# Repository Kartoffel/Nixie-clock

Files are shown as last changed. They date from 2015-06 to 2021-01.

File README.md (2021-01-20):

# Nixie-clock
DIY IN-14 Nixie clock

### Read the article at https://blankers.eu/2021/nixie-clock/

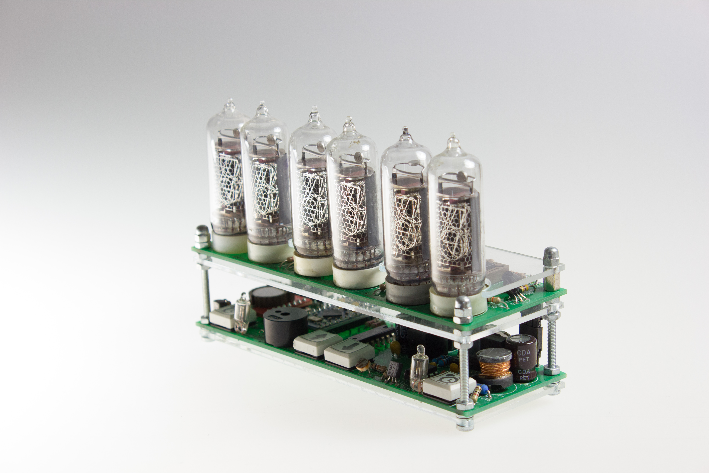
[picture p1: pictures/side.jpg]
Nixie clock


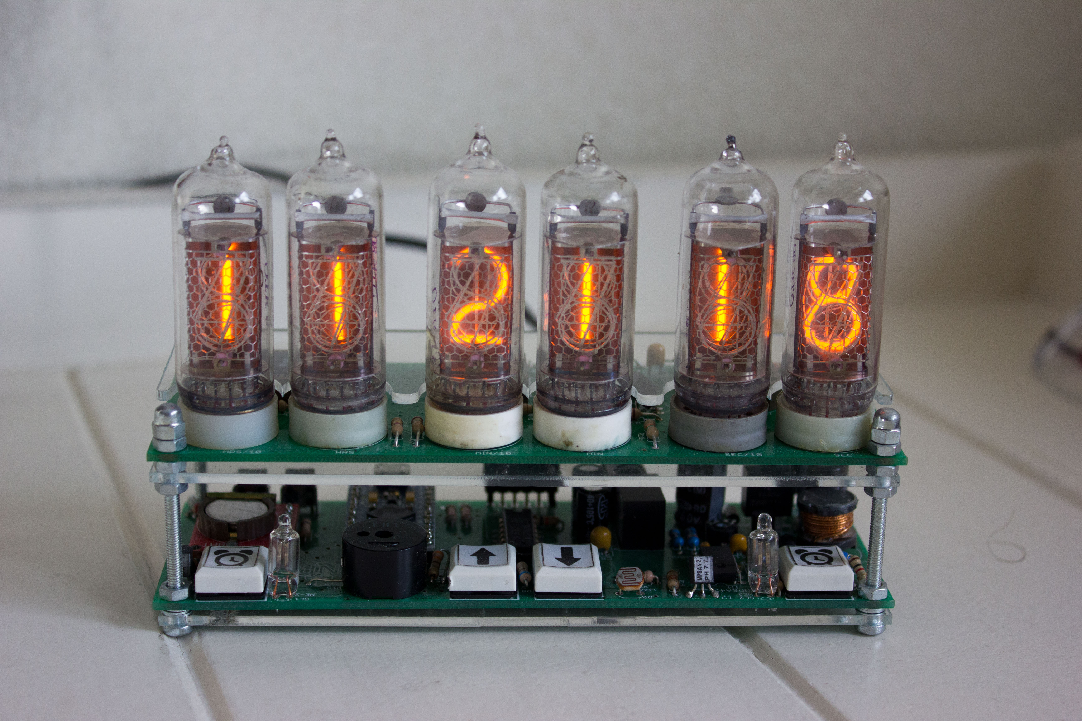
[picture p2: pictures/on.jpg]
Nixie clock in operation


<a href="http://www.youtube.com/watch?feature=player_embedded&v=HqRzXS7RQFY" target="_blank">Demonstration video</a>

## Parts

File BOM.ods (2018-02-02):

Part | Name | Part number
 | 6x Nixie tube | IN14
IC1..IC3 | VFD driver IC | HV5812PJ
T3 | PNP high voltage transistor | MPSA92
T4,T7 | NPN high voltage transistor | MPSA42
D6 | Zener diode 62V | Zen-1-3W-62V
C9 | 100nF capacitor (>62V) 0.1” | 100nF-R2-5
R4 | Resistor 390K | Kool-0W5-390k
R16 | Resistor 33K | Kool-0W5-33k
R1,R21 | Resistor 10K | Kool-0W5-10k
R13 | Resistor 470K | Kool-0W5-470k
R3,R6,R7,R10,R11,R14 | Resistor 15K | Kool-0W5-15k
R2,R15 | Resistor 120K | Kool-0W5-120k
JP2,JP3 | Pin headers 0.1” 6 pins lang | Head-6p-recht-Lang
JP2,JP3 | Pin header female 8 pins | ZL262-8
 | PCB 5x15cm 2 layers
U1 | SMPS | MC34063A
T8 | MOSFET | IRF640N
D2 | Diode | UF4007
L1 | Inductor 150uH | CH6080-150u
TR1 | Trimpot | Piher-ML-2k5
T9 | Transistor | BC516
D3 | Diode | SB140
R17 | Resistor 0R1 3W | DRG-3W-0r1
C2 | Capacitor 470uF 25V | 470uF-25V-Nichi-SE
C3,C6 | Capacitor 100nF | 100nF-R2-5
C4 | Capacitor 1nF | 1nF-R2-5
R18 | Resistor 1K | Kool-0W5-1k
R19 | Resistor 3K9 | Kool-0W5-3k9
R20 | Resistor 560K | Kool-0W5-560k
C5 | Capacitor 10uF 200V | 10uF-200V-kme
 | Power adapter 9V >=5W c. pos
JP1 | 2.1mm power jack | V-C-2mm1-DC10
U2 | Arduino pro micro
V1 | Quad 2-input AND gate | 74HCT08
IC1 | +5V LDO regulator | L4941BV
C8,C9 | Capacitor 100nF | 100nF-R2-5
C1,C7 | Capacitor 68uF | 68uF-25V-Pana-FR
R4,R5,R3 | Resistor 10K | Kool-0W5-10k
R15 | Resistor 180R | Kool-0W5-180
U3 | GeeTech RTC Module
SG1 | Buzzer | BZPN-1705
S1,S2 | Switch standing | DrukT-Haaks-Print-Wit
SW1-4 | Switch square white | Druktoets-Vierk-Print-wit
R2 | LDR | LDR-07-62
R13,R14 | Resistor 33K | Kool-0W5-33k
R1,R6 | Resistor 270K | Kool-0W5-270k
T1,T2 | High voltage transistor | MPSA42
GL1-2 | Neon bulbs | Neon-draad-15x5-8
R11,R12,R7 | Resistor 2K2 | Kool-0W5-2k2
R8 | Resistor 330R | Kool-0W5-330
R9 | Resistor 680R | Kool-0W5-680
R10 | Resistor 1K | Kool-0W5-1k
 | PCB 5x15cm 2 layers
 | Nuts/bolts/caps
 | 2mm acrylics (~15x15cm)

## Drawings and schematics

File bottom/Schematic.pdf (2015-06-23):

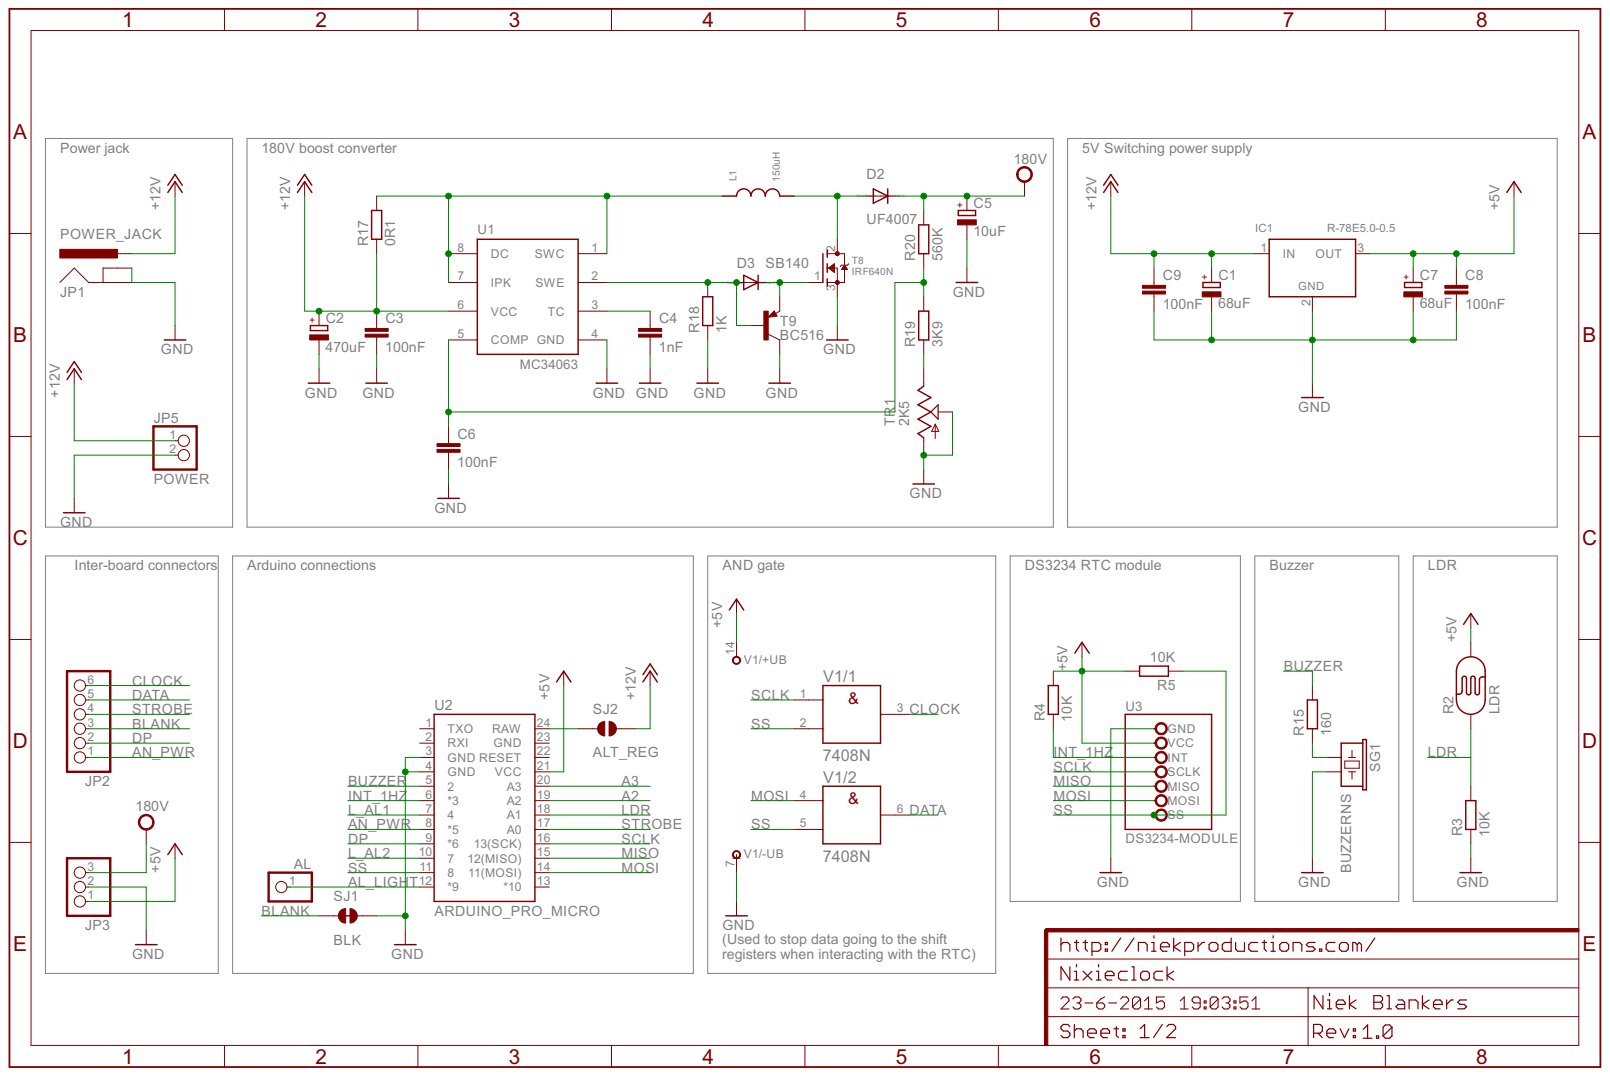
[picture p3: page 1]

GND
(Used to stop data going to the shift registers when interacting with the RTC)

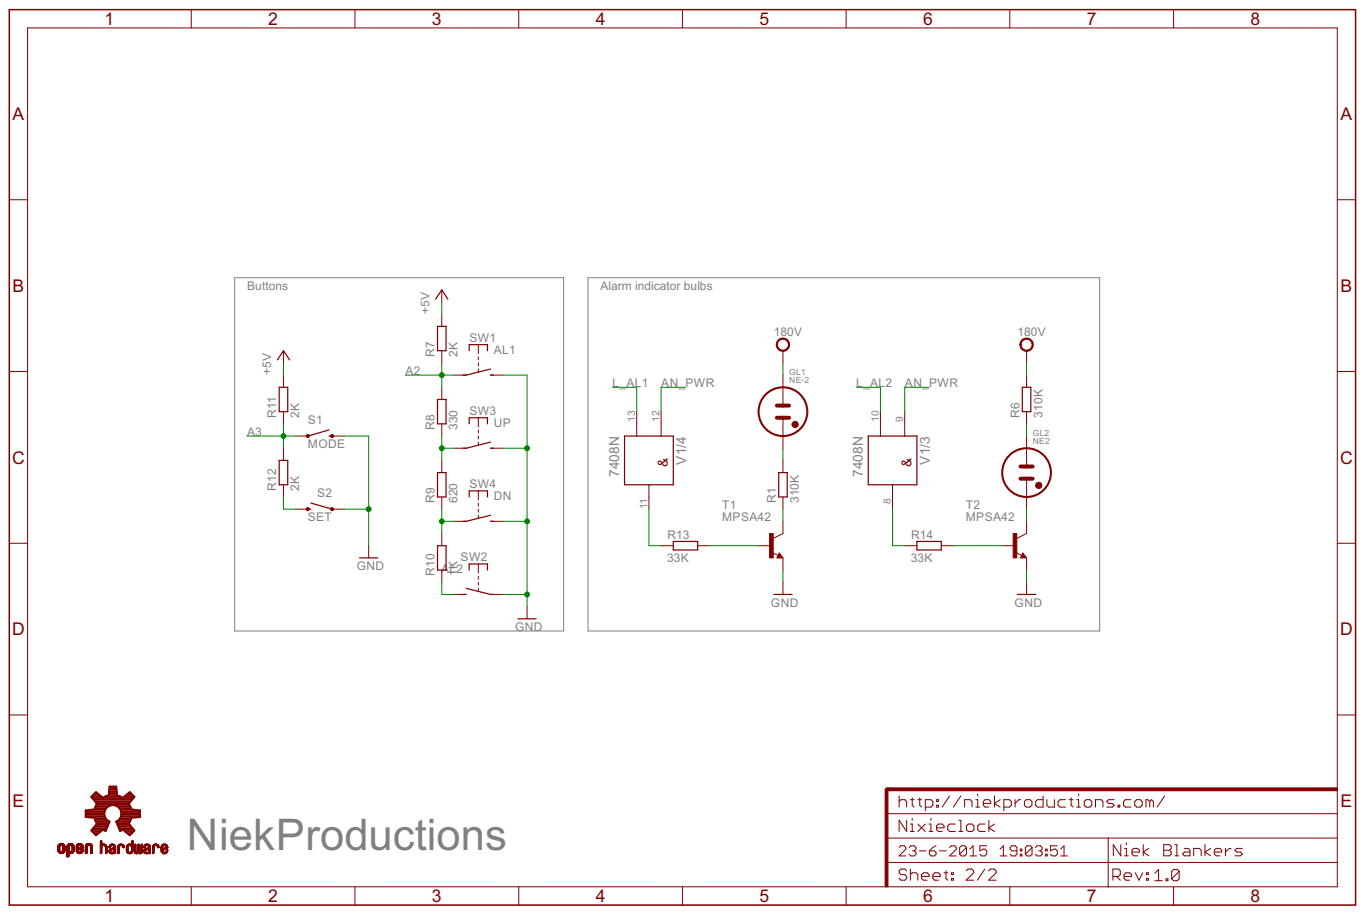
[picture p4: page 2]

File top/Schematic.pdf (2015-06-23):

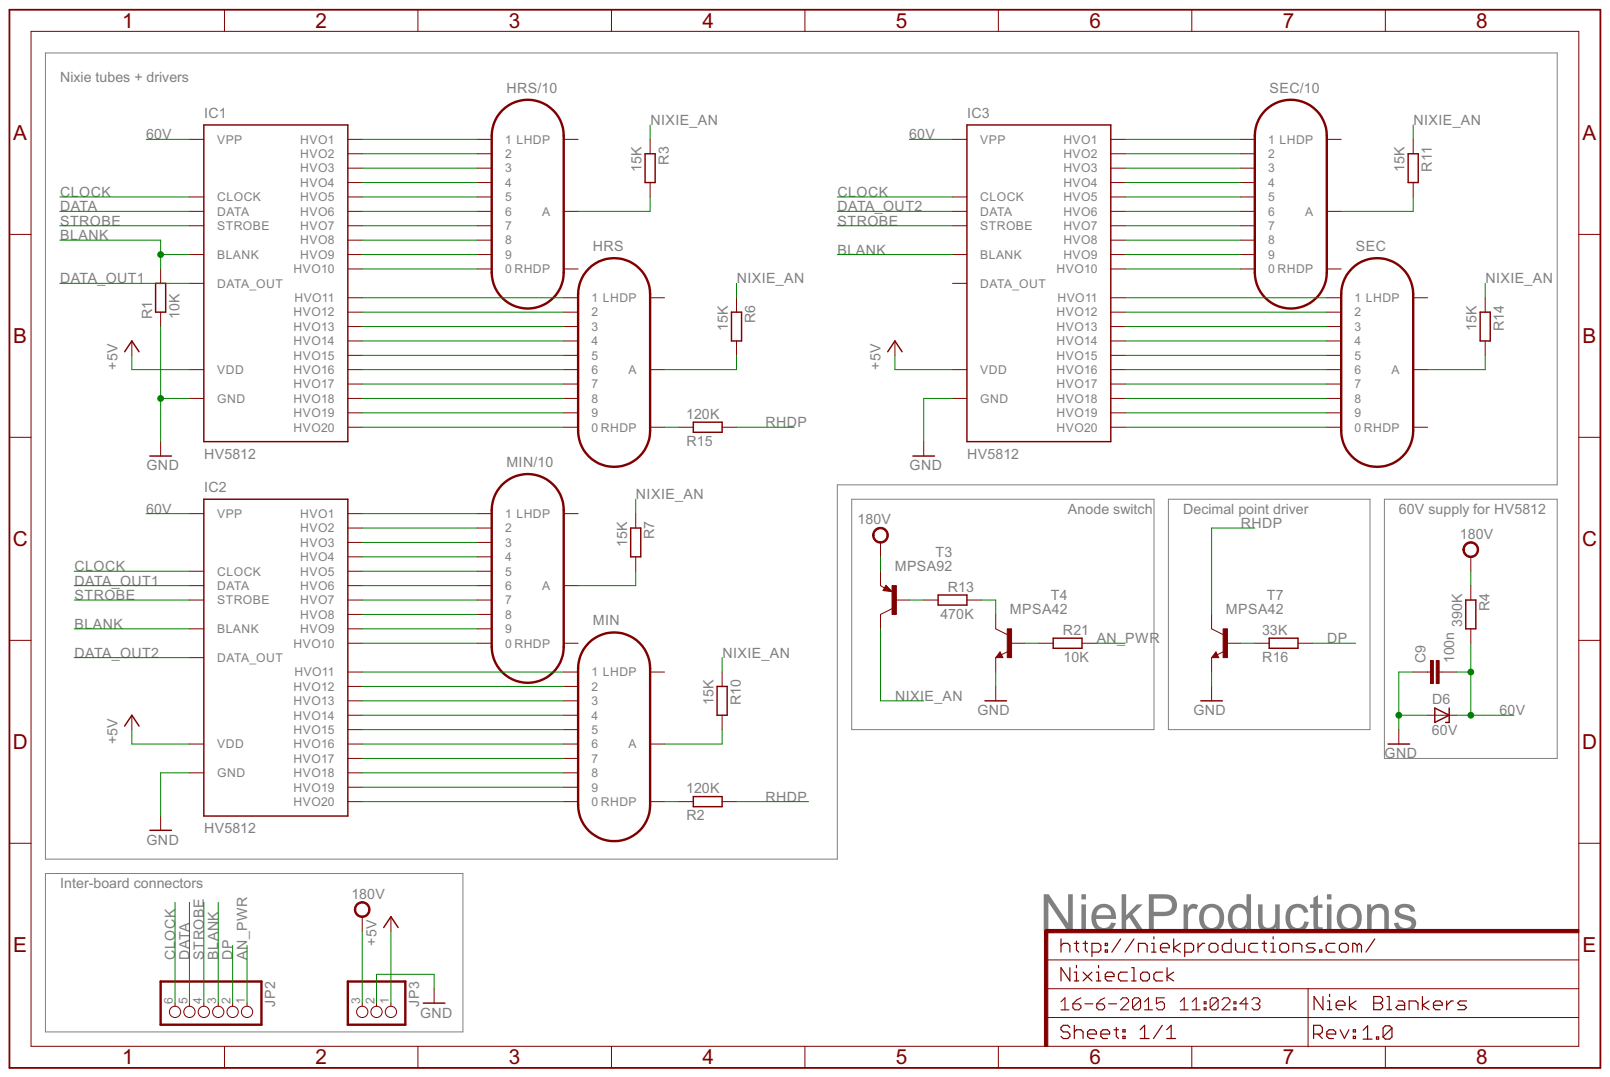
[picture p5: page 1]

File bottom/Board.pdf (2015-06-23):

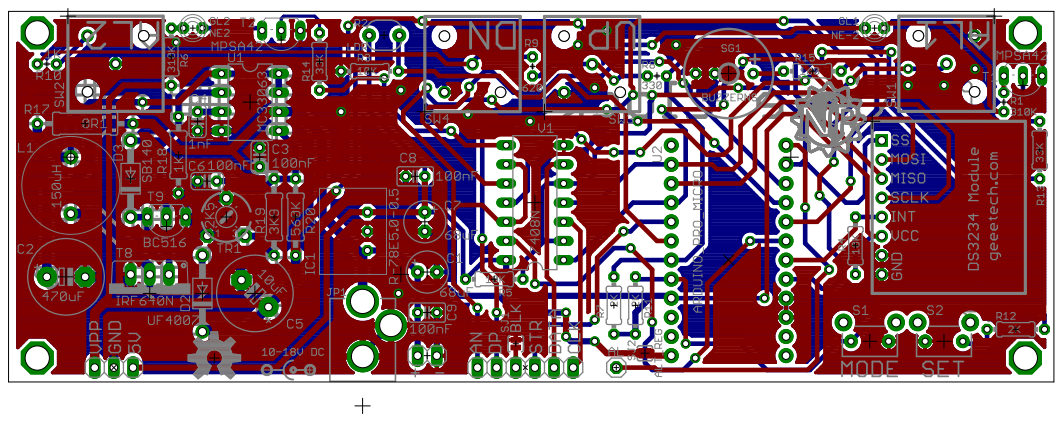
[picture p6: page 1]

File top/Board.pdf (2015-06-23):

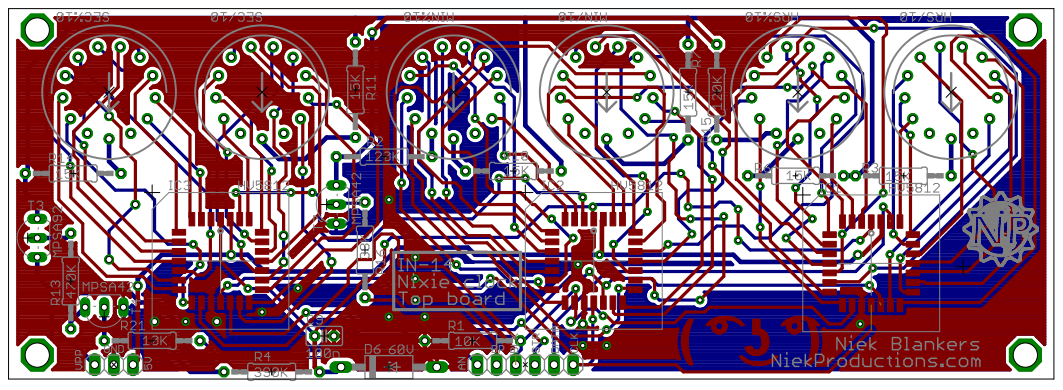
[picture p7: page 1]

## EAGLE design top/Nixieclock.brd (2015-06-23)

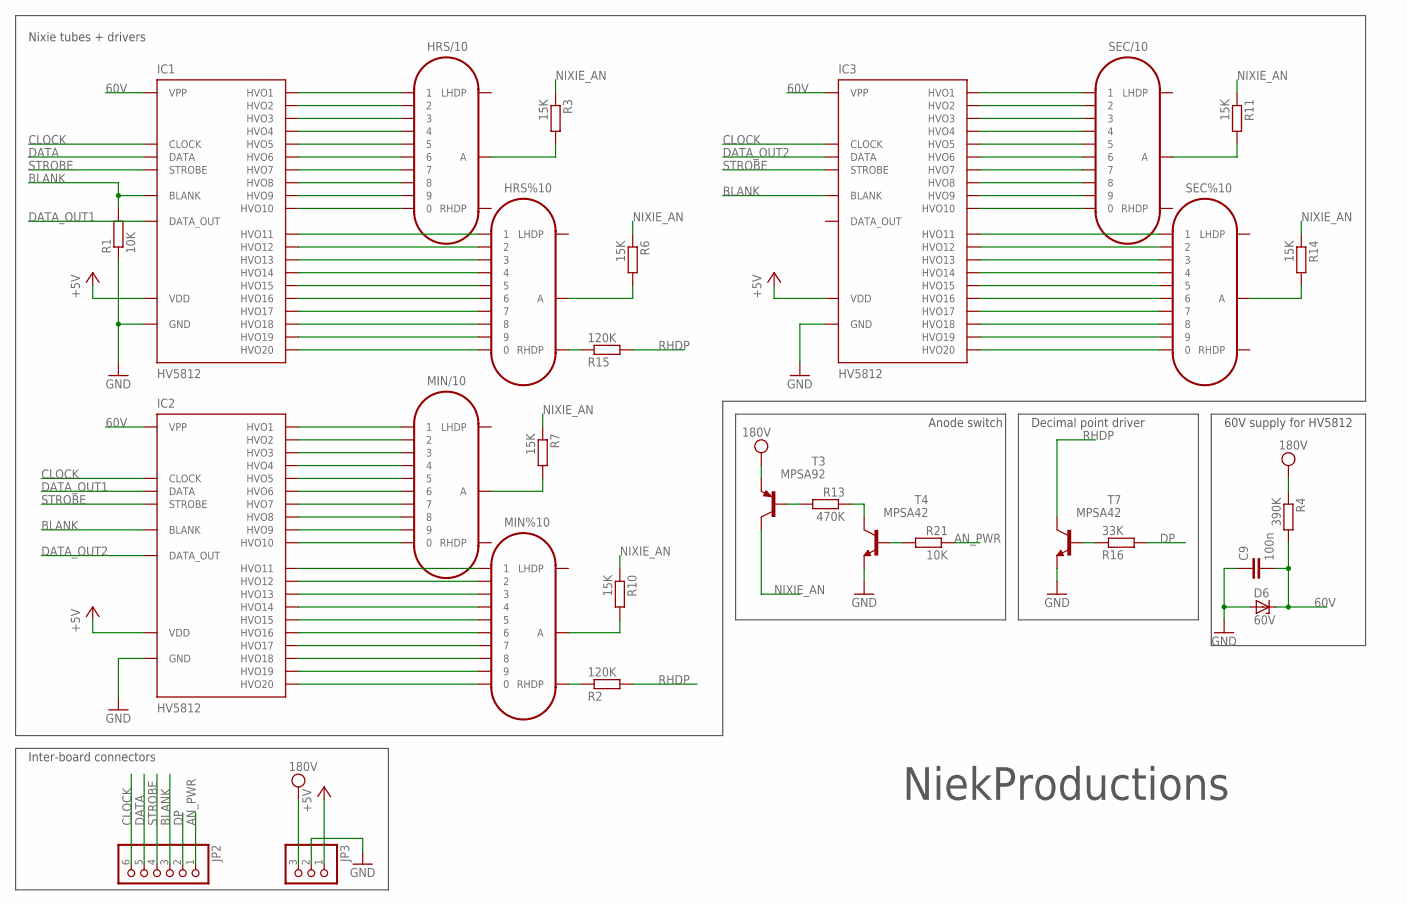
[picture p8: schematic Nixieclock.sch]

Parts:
C9: 100n; C025-025X050
D6: 60V; F126Z12
HRS%10: IN-14
HRS/10: IN-14
IC1, IC2, IC3: HV5812; PLCC-28-SMD
JP2: PINHD-1X6; 1X06
JP3: PINHD-1X3; 1X03
MIN%10: IN-14
MIN/10: IN-14
R1, R21: 10K; 0207/12
R2, R15: 120K; 0207/12
R3, R6, R7, R10, R11, R14: 15K; 0207/12
R4: 390K; 0207/12
R13: 470K; 0207/12
R16: 33K; 0207/12
SEC%10: IN-14
SEC/10: IN-14
T3: MPSA92; TO92-EBC
T4, T7: MPSA42; TO92-EBC
U$4: NPLOGO1CM-DIA; NPLOGO-1CM

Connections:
60V: C9.2, D6.C, IC1.1 (VPP), IC2.1 (VPP), IC3.1 (VPP), R4.2
+5V: IC1.28 (VDD), IC2.28 (VDD), IC3.28 (VDD), JP3.1
AN_PWR: JP2.1, R21.1
BLANK: IC1.13 (BLANK), IC2.13 (BLANK), IC3.13 (BLANK), JP2.3, R1.2
CLOCK: IC1.15 (CLOCK), IC2.15 (CLOCK), IC3.15 (CLOCK), JP2.6
DATA: IC1.27 (DATA), JP2.5
DATA_OUT1: IC1.2 (DATA_OUT), IC2.27 (DATA)
DATA_OUT2: IC2.2 (DATA_OUT), IC3.27 (DATA)
DP: JP2.2, R16.2
GND: C9.1, D6.A, IC1.14 (GND), IC2.14 (GND), IC3.14 (GND), JP3.2, R1.1, T4.E, T7.E
HVO1: HRS/10.1, IC1.26 (HVO1)
HVO2: HRS/10.2, IC1.25 (HVO2)
HVO3: HRS/10.3, IC1.24 (HVO3)
HVO4: HRS/10.4, IC1.23 (HVO4)
HVO5: HRS/10.5, IC1.22 (HVO5)
HVO6: HRS/10.6, IC1.21 (HVO6)
HVO7: HRS/10.7, IC1.20 (HVO7)
HVO8: HRS/10.8, IC1.19 (HVO8)
HVO9: HRS/10.9, IC1.18 (HVO9)
HVO10: HRS/10.0, IC1.17 (HVO10)
HVO20: IC2.3 (HVO20), MIN%10.0
unnamed: HRS%10.RHDP, R15.1
unnamed: MIN%10.RHDP, R2.1
unnamed: R16.1, T7.B
unnamed: R13.2, T3.B
unnamed: HRS/10.A, R3.2
unnamed: IC3.25 (HVO2), SEC/10.2
unnamed: IC3.23 (HVO4), SEC/10.4
unnamed: R13.1, T4.C
unnamed: R21.2, T4.B
unnamed: MIN/10.A, R7.2
unnamed: R11.2, SEC/10.A
unnamed: IC3.22 (HVO5), SEC/10.5
unnamed: HRS%10.A, R6.2
unnamed: IC3.21 (HVO6), SEC/10.6
unnamed: IC3.20 (HVO7), SEC/10.7
unnamed: IC3.19 (HVO8), SEC/10.8
unnamed: IC3.18 (HVO9), SEC/10.9
unnamed: IC3.17 (HVO10), SEC/10.0
unnamed: IC3.12 (HVO11), SEC%10.1
unnamed: IC3.11 (HVO12), SEC%10.2
unnamed: IC3.10 (HVO13), SEC%10.3
unnamed: IC3.9 (HVO14), SEC%10.4
unnamed: IC3.8 (HVO15), SEC%10.5
unnamed: IC3.7 (HVO16), SEC%10.6
unnamed: IC3.6 (HVO17), SEC%10.7
unnamed: IC3.5 (HVO18), SEC%10.8
unnamed: IC3.4 (HVO19), SEC%10.9
unnamed: MIN%10.A, R10.2
unnamed: IC3.24 (HVO3), SEC/10.3
unnamed: IC3.3 (HVO20), SEC%10.0
unnamed: IC3.26 (HVO1), SEC/10.1
unnamed: HRS%10.0, IC1.3 (HVO20)
unnamed: HRS%10.9, IC1.4 (HVO19)
unnamed: HRS%10.8, IC1.5 (HVO18)
unnamed: HRS%10.7, IC1.6 (HVO17)
unnamed: HRS%10.5, IC1.8 (HVO15)
unnamed: HRS%10.6, IC1.7 (HVO16)
unnamed: HRS%10.3, IC1.10 (HVO13)
unnamed: HRS%10.4, IC1.9 (HVO14)
unnamed: HRS%10.1, IC1.12 (HVO11)
unnamed: HRS%10.2, IC1.11 (HVO12)
unnamed: IC2.26 (HVO1), MIN/10.1
unnamed: IC2.25 (HVO2), MIN/10.2
unnamed: R14.2, SEC%10.A
unnamed: IC2.24 (HVO3), MIN/10.3
unnamed: IC2.23 (HVO4), MIN/10.4
unnamed: IC2.22 (HVO5), MIN/10.5
unnamed: IC2.21 (HVO6), MIN/10.6
unnamed: IC2.20 (HVO7), MIN/10.7
unnamed: IC2.19 (HVO8), MIN/10.8
unnamed: IC2.18 (HVO9), MIN/10.9
unnamed: IC2.17 (HVO10), MIN/10.0
unnamed: IC2.12 (HVO11), MIN%10.1
unnamed: IC2.11 (HVO12), MIN%10.2
unnamed: IC2.10 (HVO13), MIN%10.3
unnamed: IC2.9 (HVO14), MIN%10.4
unnamed: IC2.8 (HVO15), MIN%10.5
unnamed: IC2.7 (HVO16), MIN%10.6
unnamed: IC2.6 (HVO17), MIN%10.7
unnamed: IC2.5 (HVO18), MIN%10.8
unnamed: IC2.4 (HVO19), MIN%10.9
NIXIE_AN: R3.1, R6.1, R7.1, R10.1, R11.1, R14.1, T3.C
RHDP: R2.2, R15.2, T7.C
STROBE: IC1.16 (STROBE), IC2.16 (STROBE), IC3.16 (STROBE), JP2.4
VPP: JP3.3, R4.1, T3.E

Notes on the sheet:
Decimal point driver
Nixie tubes + drivers
Inter-board connectors
Anode switch
60V supply for HV5812

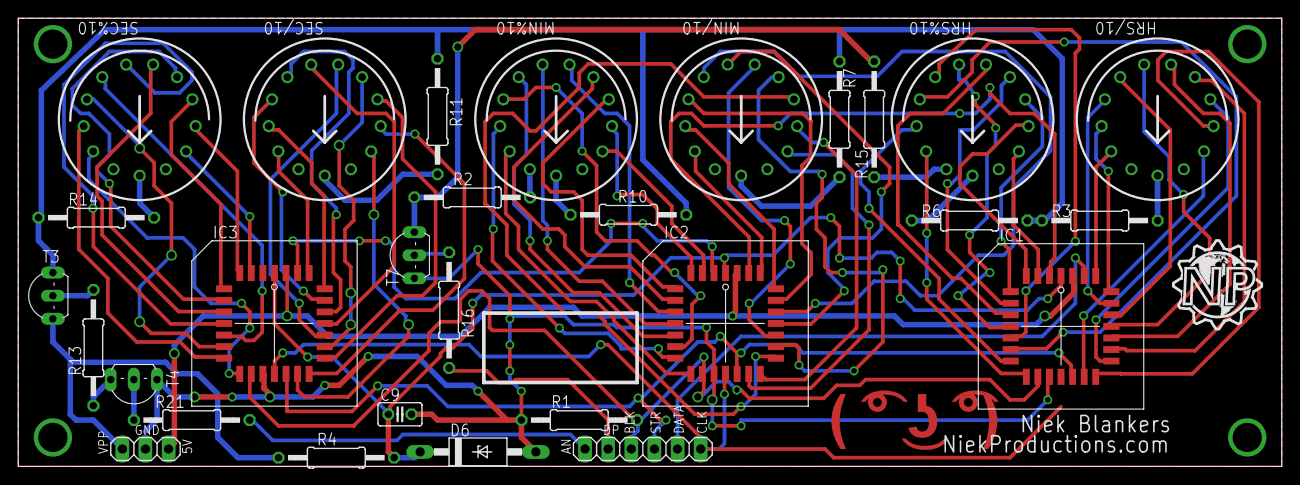
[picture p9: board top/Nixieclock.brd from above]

Board: 2 copper layers, 138.7 x 49.2 mm, 31 parts (1 on the bottom side), 86 nets.

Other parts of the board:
U$5: LENNY

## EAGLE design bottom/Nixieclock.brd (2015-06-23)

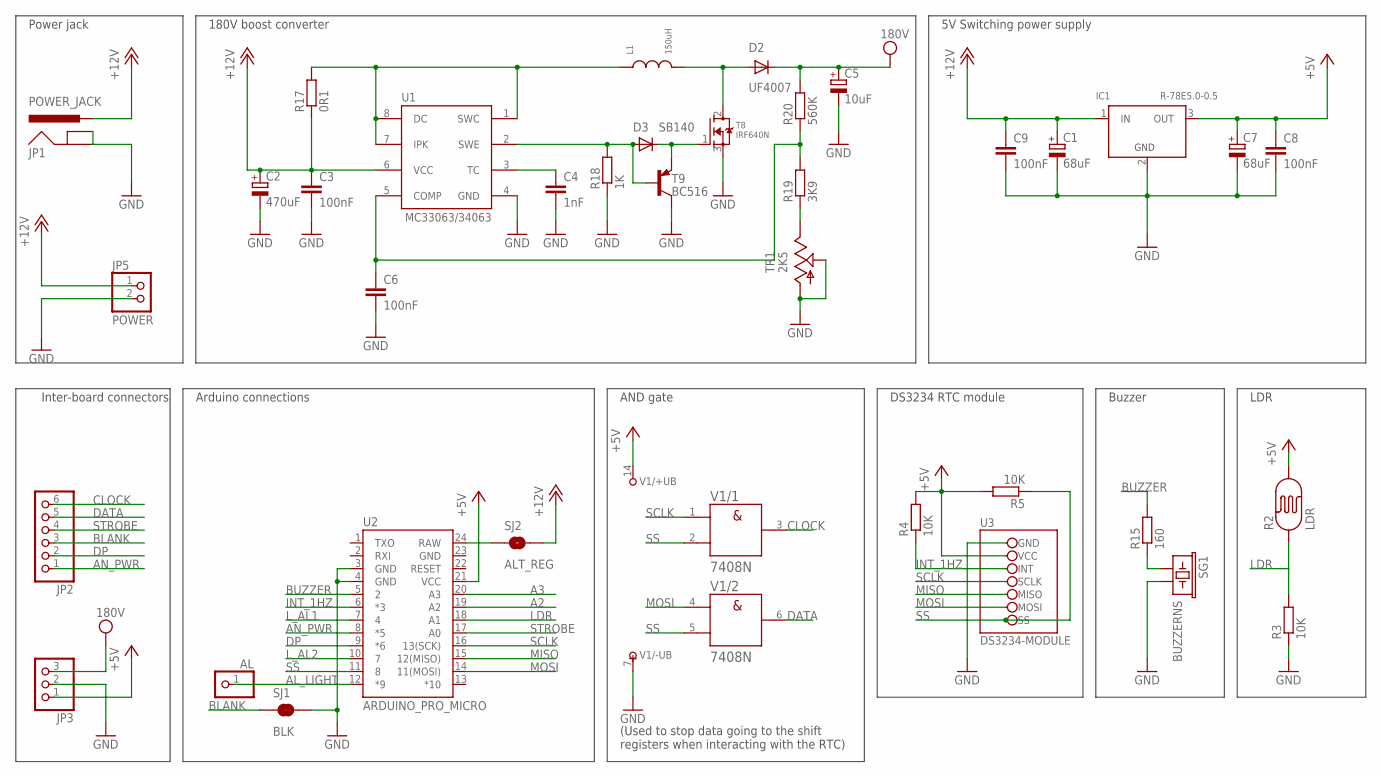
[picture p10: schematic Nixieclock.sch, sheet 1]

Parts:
AL: PINHD-1X1; 1X01
C1, C7: 68uF; E2,5-6
C2: 470uF; E5-10,5
C3, C6: 100nF; C025-024X044
C4: 1nF; C025-024X044
C5: 10uF; E5-10,5
C8, C9: 100nF; C025-025X050
D2: UF4007; DO41-10
D3: SB140; DO41-10
IC1: R-78E5.0-0.5; R-78E
JP1: POWER_JACK; POWER_JACK_PTH_LOCK
JP2: PINHD-1X6; 1X06
JP3: PINHD-1X3; 1X03
JP5: POWER; 1X02
L1: 150uH; INDUCTOR
R2: LDR; PHOTOCELL
R3, R4, R5: 10K; 0204/7
R15: 160; 0204/7
R17: 0R1; 0309/12
R18: 1K; 0207/10
R19: 3K9; 0207/10
R20: 560K; 0207/10
SG1: BUZZERNS; BUZZER-12MM-NS
SJ1: BLK; PAD-JUMPER-2-NC_BY_TRACE_YES_SILK
SJ2: ALT_REG; SJ_2S-NO
T8: IRF640N; TO220V
T9: BC516; TO92-EBC
TR1: 2K5; 6MM
U1: MC33063; DIL08
U2: ARDUINO_PRO_MICRO
U3: DS3234-MODULE; GEETECH-DS3234
V1: 7408N; DIL14

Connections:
+5V: C7.+, C8.1, IC1.3 (OUT), JP3.1, R2.2, R4.2, R5.2, U2.21 (VCC), U3.VCC, V1.14 (+UB); also elsewhere on the board
+12V: C1.+, C2.+, C3.1, C9.1, IC1.1 (IN), JP1.PWR, JP5.1, R17.1, SJ2.2, U1.6 (VCC)
A2: U2.19 (A2); also elsewhere on the board
A3: U2.20 (A3); also elsewhere on the board
AL_LIGHT: AL.1, U2.12 (*9)
AN_PWR: JP2.1, U2.8 (*5); also elsewhere on the board
BLANK: JP2.3, SJ1.1
BUZZER: R15.2, U2.5 (2)
CLOCK: JP2.6, V1.3 (Y)
DATA: JP2.5, V1.6 (Y)
DP: JP2.2, U2.9 (*6)
GND: C1.-, C2.-, C3.2, C4.2, C5.-, C6.2, C7.-, C8.2, C9.2, IC1.2 (GND), JP1.GND, JP1.GNDBREAK, JP3.2, JP5.2, R3.1, R18.1, SG1.- (2), SG1.-- (2), SJ1.2, T8.3 (S), T9.C, TR1.A, TR1.S, U1.4 (GND), U2.3 (GND), U2.4 (GND), U3.GND~1 (GND), U3.GND~2 (GND), V1.7 (-UB); also elsewhere on the board
INT_1HZ: R4.1, U2.6 (*3), U3.INT
LDR: R2.1, R3.2, U2.18 (A1)
L_AL1: U2.7 (4); also elsewhere on the board
L_AL2: U2.10 (7); also elsewhere on the board
MISO: U2.15 (12(MISO)), U3.MISO
MOSI: U2.14 (11(MOSI)), U3.MOSI, V1.4 (A)
unnamed: D3.A, R18.2, T9.B, U1.2 (SWE)
unnamed: D3.C, T8.1 (G), T9.E
unnamed: C4.1, U1.3 (TC)
unnamed: L1.P$1, R17.2, U1.1 (SWC), U1.7 (IPK), U1.8 (DC)
unnamed: D2.A, L1.P$2, T8.2 (D)
unnamed: C6.1, R19.2, R20.1, U1.5 (COMP)
unnamed: R19.1, TR1.E
unnamed: SJ2.1, U2.24 (RAW)
unnamed: R15.1, SG1.+ (1)
SCLK: U2.16 (13(SCK)), U3.SCLK, V1.1 (A)
SS: R5.1, U2.11 (8), U3.SS, V1.2 (B), V1.5 (B)
STROBE: JP2.4, U2.17 (A0)
VPP: C5.+, D2.C, JP3.3, R20.2; also elsewhere on the board

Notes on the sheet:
180V boost converter
Inter-board connectors
Power jack
5V Switching power supply
Arduino connections
LDR
AND gate
(Used to stop data going to the shift registers when interacting with the RTC)
Buzzer
DS3234 RTC module

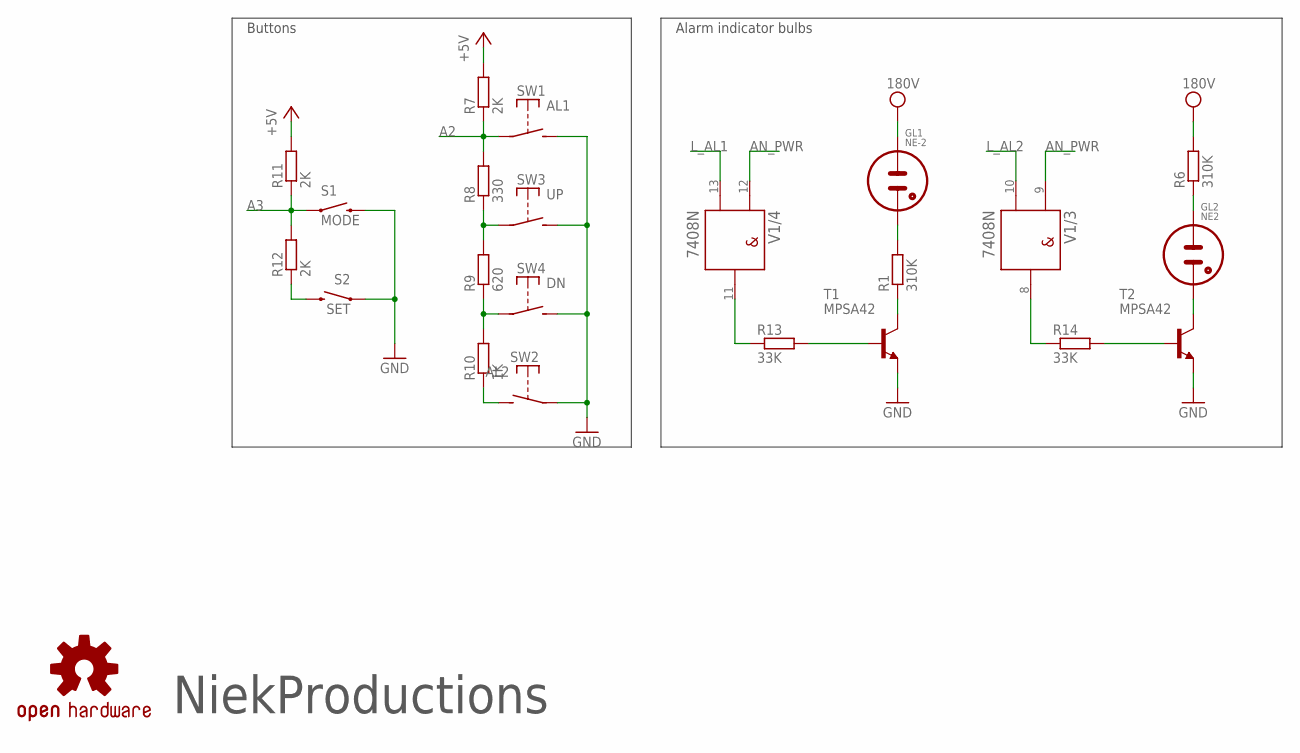
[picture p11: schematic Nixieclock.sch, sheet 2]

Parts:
GL1: NE-2; NE2-NEON-BULB-DRILL
GL2: NE2; NE2-NEON-BULB-DRILL
LOGO2: OSHW-LOGOL; OSHW-LOGO-L
R1: 310K; 0204V
R6: 310K; 0204/7
R7, R11, R12: 2K; 0204/7
R8: 330; 0204V
R9: 620; 0204V
R10: 1K; 0204V
R13, R14: 33K; 0204/7
S1: MODE; TACTILE-PTH-SIDEEZ
S2: SET; TACTILE-PTH-SIDEEZ
SW1: AL1; SW-12.65MM-SQ-WHITE
SW2: AL2; SW-12.65MM-SQ-WHITE
SW3: UP; SW-12.65MM-SQ-WHITE
SW4: DN; SW-12.65MM-SQ-WHITE
T1, T2: MPSA42; TO92-EBC
U$4: NPLOGO1CM-DIA; NPLOGO-1CM
V1: 7408N; DIL14

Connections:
+5V: R7.2, R11.2; also elsewhere on the board
A2: R7.1, R8.2, SW1.SW-CENTER; also elsewhere on the board
A3: R11.1, R12.2, S1.1; also elsewhere on the board
AN_PWR: V1.9 (A), V1.12 (A); also elsewhere on the board
GND: S1.2, S2.1, SW1.SW-OUTSIDE (S), SW2.SW-CENTER, SW3.SW-OUTSIDE (S), SW4.SW-OUTSIDE (S), T1.E, T2.E; also elsewhere on the board
L_AL1: V1.13 (B); also elsewhere on the board
L_AL2: V1.10 (B); also elsewhere on the board
unnamed: R13.2, T1.B
unnamed: R14.2, T2.B
unnamed: R12.1, S2.2
unnamed: R9.1, R10.2, SW4.SW-CENTER
unnamed: R8.1, R9.2, SW3.SW-CENTER
unnamed: R10.1, SW2.SW-OUTSIDE (S)
unnamed: R1.1, T1.C
unnamed: GL2.2 (A1), T2.C
unnamed: GL1.2 (A1), R1.2
unnamed: GL2.1 (A), R6.1
unnamed: R13.1, V1.11 (Y)
unnamed: R14.1, V1.8 (Y)
VPP: GL1.1 (A), R6.2; also elsewhere on the board

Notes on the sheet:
Alarm indicator bulbs
Buttons

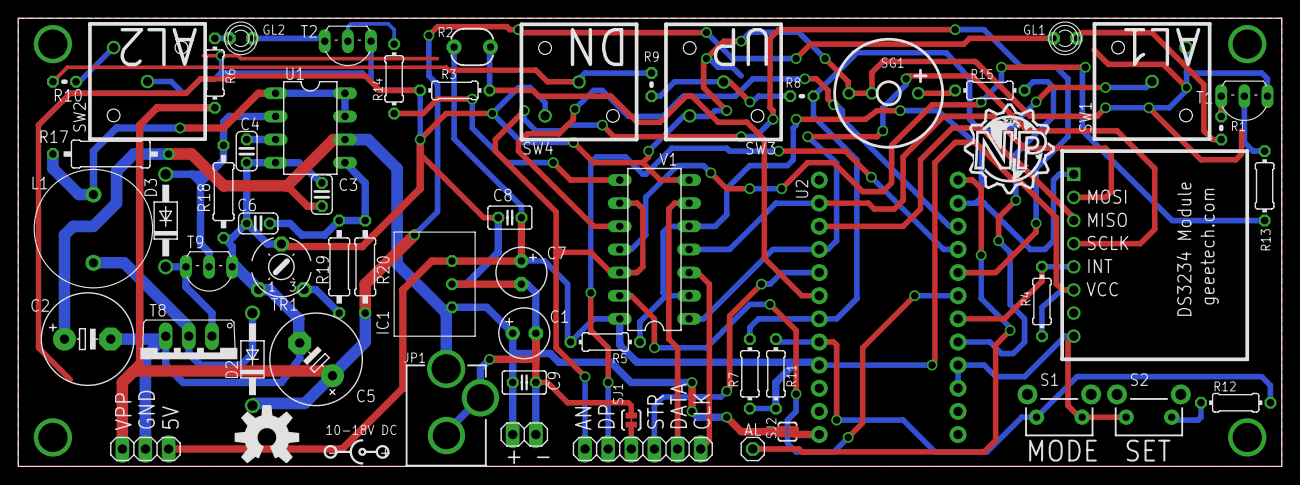
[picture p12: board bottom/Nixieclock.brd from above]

Board: 2 copper layers, 138.7 x 49.2 mm, 59 parts (0 on the bottom side), 43 nets.

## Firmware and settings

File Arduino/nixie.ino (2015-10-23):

/** Arduino source code
 * Nixie clock
 * Author: Niek Blankers <niek@niekproductions.com>
 *
 * 6 Digit IN-14 Nixie clock
 * Uses Arduino Pro Micro with HV5812, DS3234.
 */
#include <SPI.h>
#include <avr/eeprom.h>

// #define DEBUG

// SPI pins
const int   csPin           =   8;
const int   strobePin       =   A0;
const int   dataPin         =   16; // mega32u4 MOSI - PB2
const int   clkPin          =   15; // mega32u4 SCK - PB1

// Anode driver, used for dimming
const int   anodes          =   5;
const int   minBrightness   =   55;
const int   maxBrightness   =   100;
int         lastBrightness  =   minBrightness;

// Light sensor settings
const int   ldrPin          =   A1;
const int   ldrDark         =   80;
const int   ldrBright       =   830;

const int   frontButtons    =   A2;
const int   rearButtons     =   A3;

// Analog values for frontButtons
const int   al1ButtonVal    =   0;
const int   upButtonVal     =   132;
const int   downButtonVal   =   320;
const int   al2ButtonVal    =   487;
// Analog values for rearButtons
const int   setButtonVal    =   502;
const int   modeButtonVal   =   0;
// The analog readings can differ this much from the values above
const int   buttonRange     =   10;

const int   al1Button       =   1;
const int   upButton        =   2;
const int   downButton      =   3;
const int   al2Button       =   4;
const int   setButton       =   5;
const int   modeButton      =   6;
// Debounce time for buttons (ms)
const int   buttonDebounce  =   200;

const int   decimalPoint    =   6;

// Alarm indicator bulbs
const int   al1Light        =   4;
const int   al2Light        =   7;

const int   buzzerPin       =   2;

// Number of seconds after which to switch between date and time
const int   switchInterval  =   5;

const int   fadeDuration    =   150;

int         date[3]         =   { 1, 1, 0 };
int         time[3]         =   { 0, 0, 0 };
int         prevTime[3]     =   { 0, 0, 0 };

// Enable automatic DST switching (+1 hour between october and march)
const bool  enableDST       =   true;
bool        lastDST;

struct alarmSettings_t{
    bool    al1Enabled;
    bool    al2Enabled;

    int     al1Time[2];
    int     al2Time[2];
} alarmSettings;

// The number of steps between the output being on and off
const int   dimFactor       =   100;
// Factor that's used for true dimming (exponential)
// From https://diarmuid.ie/blog/pwm-exponential-led-fading-on-arduino-or-other-platforms/
float       R;

// Data to send to shift register, MSB first
const short numbers[10] = {
    0b1111111110,
    0b0111111111,
    0b1011111111,
    0b1101111111,
    0b1110111111,
    0b1111011111,
    0b1111101111,
    0b1111110111,
    0b1111111011,
    0b1111111101
};

const short blank                   = 0b1111111111;

// Operating modes
const int   MODE_DISPLAY_TIME       =   0;
const int   MODE_DISPLAY_DATETIME   =   1;
const int   MODE_SET                =   2;
// Volatile - modified in interrupt function as well as loop
volatile int mode                   =   MODE_DISPLAY_TIME;

const int   day             =   0;
const int   month           =   1;
const int   year            =   2;

const int   hours           =   0;
const int   minutes         =   1;
const int   seconds         =   2;

const int   thisCentury     =   2000;

// Enter cathode cleaning mode
volatile bool doCleanCathodes  =   false;

const int   fadeSteps      =   50;

void setup(){
    setupNixies();
    clearDisplay();

    RTC_init();

    // DS3234 SQW output
    attachInterrupt(0, updateTime, FALLING);

    pinMode(ldrPin, INPUT);

    pinMode(buzzerPin, OUTPUT);
    digitalWrite(buzzerPin, LOW);

    loadAlarmSettings();

    start_SPI();
    readDateTime();
    stop_SPI();

    lastDST = isDST(date);

    // Calculate the R factor for exponential dimming
    R = dimFactor * log10(2) / log10(255);

#ifdef DEBUG
    Serial.begin(9600);
    // Necessary for Leonardo
    while (!Serial);
#endif
}

void updateTime(){
    start_SPI();
    // Read Date/Time from RTC
    readDateTime();
    // Adjust time for DST
    if(enableDST)
        adjustDST();
    stop_SPI();

    // Prevent cathode poisoning
    doCleanCathodes = (
        (time[minutes] % 20) == 0
        && time[seconds] < 3
        && mode != MODE_SET
    );

    if(!doCleanCathodes)
        updateDisplay();

    memcpy(prevTime, time, sizeof(time));
}

void updateDisplay(){
    switch(mode){
        case MODE_DISPLAY_TIME:
            // Display time
            fadeTo(time, prevTime, fadeDuration);
            digitalWrite(decimalPoint, LOW);
            break;
        case MODE_DISPLAY_DATETIME:
            // Display time and date
            if ((time[seconds] / switchInterval) % 2 == 0) {
                if ((float) time[seconds] / switchInterval == 0.0)
                    displayTime(time);
                else
                    fadeTo(time, prevTime, fadeDuration);
                digitalWrite(decimalPoint, LOW);
            } else {
                displayTime(date);
                digitalWrite(decimalPoint, !(time[seconds] % 2));
            }
            break;
    }
}

void loop(){
    updateBrightness();

    handleButtons();

    handleAlarms();

    while (doCleanCathodes) {
        cleanCathodes();
        delay(100);
    }

    delay(15);
}

// Find the day of the week (0 = sun, 6 = sat)
// By Michael Keith & Tom Craver
// https://cs.uwaterloo.ca/~alopez-o/math-faq/node73.html
int DOW(int *date){
    int d = date[day];
    int m = date[month];
    int y = date[year] + thisCentury;

    return (d+=m<3?y--:y-2,23*m/9+d+4+y/4-y/100+y/400)%7;
}

bool isLeapYear(int *date){
    if(date[year] % 400 == 0) return true;
    if(date[year] % 100 == 0) return false;
    return (date[year] % 4 == 0);
}

// Check if Daylight saving time (DST) applies
// Northern Hemisphere - +1 hour between March and October
bool isDST(int *date){
    bool dst = false;
    int d = date[day];
    int m = date[month];
    int y = date[year] + thisCentury;

    dst = (m > 3 && m < 10); // October-March

    if (m == 3){
        // Last sunday of March
        dst = (d >= ((31 - (5 * y /4 + 4) % 7)));
    }else if (m == 10){
        // Last sunday of October
        dst = (d < ((31 - (5 * y /4 + 1) % 7)));
    }

    return dst;
}

// Adjust time for DST
// Northern Hemisphere - +1 hour between March and October
void adjustDST(){
    if(lastDST == isDST(date))
        return;

    if(isDST(date)){
        if(time[hours] == 2){
            time[hours]++;
            lastDST = true;
            setDateTime(date, time);
        }
    }else{
        if(time[hours] == 3){
            time[hours]--;
            lastDST = false;
            setDateTime(date, time);
        }
    }
}

void saveAlarmSettings(){
    eeprom_write_block(
        (const void*)&alarmSettings,
        (void*)0, sizeof(alarmSettings)
    );
}

void loadAlarmSettings(){
    eeprom_read_block(
        (void*)&alarmSettings,
        (void*)0, sizeof(alarmSettings)
    );

    restrictAlarm(alarmSettings.al1Time);
    restrictAlarm(alarmSettings.al2Time);

    digitalWrite(al1Light, alarmSettings.al1Enabled);
    digitalWrite(al2Light, alarmSettings.al2Enabled);
}

void handleAlarms(){
    if (
        alarmSettings.al1Enabled
        && time[hours] == alarmSettings.al1Time[hours]
        && time[minutes] == alarmSettings.al1Time[minutes]
        && time[seconds] == 0
    ) {
        while (alarmSettings.al1Enabled) {
            digitalWrite(buzzerPin, millis() % 1000 < 500);
            handleButtons();
        }
        digitalWrite(buzzerPin, LOW);
        delay(1000);
    }

    if (
        alarmSettings.al2Enabled
        && time[hours] == alarmSettings.al2Time[hours]
        && time[minutes] == alarmSettings.al2Time[minutes]
        && time[seconds] == 0
    ) {
        while (alarmSettings.al2Enabled) {
            digitalWrite(buzzerPin, millis() % 1000 < 500);
            handleButtons();
        }
        digitalWrite(buzzerPin, LOW);
        delay(1000);
    }

    digitalWrite(buzzerPin, LOW);
}

void handleButtons(){
    switch (buttonPressed()) {
        case setButton:
            if (buttonIsHeld(setButton) )
                changeDateTime();
            break;
        case modeButton:
            if (mode == MODE_DISPLAY_DATETIME)
                mode = MODE_DISPLAY_TIME;
            else if (mode == MODE_DISPLAY_TIME)
                mode = MODE_DISPLAY_DATETIME;
            delay(buttonDebounce);
            break;
        case al1Button:
            if (buttonIsHeld( al1Button)) {
                setAlarm(1);
            } else {
                if (alarmSettings.al1Enabled)
                    disableAlarm(1);
                else
                    enableAlarm(1);
            }
            break;
        case al2Button:
            if (buttonIsHeld( al2Button)) {
                setAlarm(2);
            }else{
                if (alarmSettings.al2Enabled)
                    disableAlarm(2);
                else
                    enableAlarm(2);
            }
            break;
    }
}

bool buttonIsHeld(int button){
    int buttonHeldFor = 0;
    while (buttonPressed() == button) {
        // Increase by 20 since readAvgAnalog takes ~10ms
        buttonHeldFor += 20;
        delay(10);
        if (buttonHeldFor > 800)
            return true;
    }
    return false;
}

void enableAlarm(int alarm){
    int prevMode = mode;
    mode = MODE_SET;

    int timeDisplay[3] = { 0, 0, 100};

    if( alarm == 1 ){
        memcpy(
            timeDisplay,
            alarmSettings.al1Time,
            sizeof(alarmSettings.al1Time)
        );
        alarmSettings.al1Enabled = true;
        digitalWrite(al1Light, HIGH);
    }else{
        memcpy(
            timeDisplay,
            alarmSettings.al2Time,
            sizeof(alarmSettings.al2Time)
        );
        alarmSettings.al2Enabled = true;
        digitalWrite(al2Light, HIGH);
    }

    displayTime(timeDisplay);
    saveAlarmSettings();

    delay(800);

    displayTime(time);
    mode = prevMode;
}

void disableAlarm(int alarm){
    if (alarm == 1) {
        alarmSettings.al1Enabled = false;
        digitalWrite(al1Light, LOW);
    } else {
        alarmSettings.al2Enabled = false;
        digitalWrite(al2Light, LOW);
    }
    saveAlarmSettings();
}

void setAlarm(int alarm){
    int prevMode = mode;
    mode = MODE_SET;

    int newAlarm[2];

    if (alarm == 1)
        memcpy(
            newAlarm,
            alarmSettings.al1Time,
            sizeof(alarmSettings.al1Time)
        );
    else
        memcpy(
            newAlarm,
            alarmSettings.al2Time,
            sizeof(alarmSettings.al2Time)
        );

    int timeDisplay[3] = { 0, 0, 100 };
    memcpy(
        timeDisplay,
        newAlarm,
        sizeof(newAlarm)
    );
    displayTime(timeDisplay);

    while (buttonPressed() == al1Button || buttonPressed() == al2Button) {};

    for (int i=0; i<2; i++) {
        while (buttonPressed() != al1Button && buttonPressed() != al2Button) {
            int activeButton = buttonPressed();
            int toAdd = 0;

            if (activeButton == upButton)
                toAdd = 1;
            else if (activeButton == downButton)
                toAdd = -1;

            newAlarm[i] += toAdd;
            restrictAlarm(newAlarm);
            memcpy(
                timeDisplay,
                newAlarm,
                sizeof(newAlarm)
            );
            if (millis() % 1000 < 500)
                timeDisplay[i] = 100;

            displayTime(timeDisplay);
            delay( abs(toAdd) * buttonDebounce );
        }
        delay(buttonDebounce);
    }

    if (alarm == 1) {
        memcpy(
            alarmSettings.al1Time,
            newAlarm,
            sizeof(newAlarm)
        );
        alarmSettings.al1Enabled = true;
        digitalWrite(al1Light, HIGH);
    } else {
        memcpy(
            alarmSettings.al2Time,
            newAlarm,
            sizeof(newAlarm)
        );
        alarmSettings.al2Enabled = true;
        digitalWrite(al2Light, HIGH);
    }
    saveAlarmSettings();
    displayTime(time);
    mode = prevMode;
}

void restrictAlarm(int newAlarm[2]){
    if (newAlarm[hours] > 23) newAlarm[hours] = 0;
    else if (newAlarm[hours] < 0) newAlarm[hours] = 23;

    if (newAlarm[minutes] > 59) newAlarm[minutes] = 0;
    else if (newAlarm[minutes] < 0) newAlarm[minutes] = 59;
}

void disableInterrupts(){
    detachInterrupt(0);
}

void enableInterrupts(){
    attachInterrupt(0, updateTime, FALLING);
}

void changeDateTime(){
    disableInterrupts();

    int newDate[3];
    int newTime[3];

    memcpy(
        newDate,
        date,
        sizeof(date)
    );
    memcpy(
        newTime,
        time,
        sizeof(time)
    );

    int prevMode = mode;
    mode = MODE_SET;

    digitalWrite(decimalPoint, HIGH);
    displayTime(newDate);

    while (buttonPressed() == setButton) {};

    for (int i=0; i<6; i++) {
        while (buttonPressed() != setButton) {
            int activeButton = buttonPressed();
            int toAdd = 0;

            if (activeButton == upButton) {
                toAdd = 1;
            } else if (activeButton == downButton) {
                toAdd = -1;
            }

            int timeDisplay[3];

            if ( i < 3 ) {
                newDate[i] += toAdd;
                restrictDate(newDate);

                digitalWrite(decimalPoint, HIGH);

                memcpy(
                    timeDisplay,
                    newDate,
                    sizeof(newDate)
                );
                if (millis() % 1000 < 500)
                    // Blank digit
                    timeDisplay[i] = 100;
            } else {
                newTime[i-3] += toAdd;
                restrictTime(newTime);

                digitalWrite(decimalPoint, LOW);

                memcpy(
                    timeDisplay,
                    newTime,
                    sizeof(newTime)
                );
                if(millis() % 1000 < 500)
                    timeDisplay[i-3] = 100;

            }

            displayTime(timeDisplay);

            delay( abs(toAdd) * buttonDebounce );
        }
        delay(buttonDebounce);
    }

    start_SPI();
    setDateTime(newDate, newTime);
    stop_SPI();

    lastDST = isDST(newDate);

    mode = prevMode;

    enableInterrupts();
}

void restrictTime(int newTime[3]){
    if (newTime[hours] > 23) newTime[hours] = 0;
    else if (newTime[hours] < 0) newTime[hours] = 23;

    if (newTime[minutes] > 59) newTime[minutes] = 0;
    else if (newTime[minutes] < 0) newTime[minutes] = 59;

    if (newTime[seconds] > 59) newTime[seconds] = 0;
    else if (newTime[seconds] < 0) newTime[seconds] = 59;
}

void restrictDate(int newDate[3]){
    if (newDate[day] > 31) newDate[day] = 1;
    else if (newDate[day] < 1) newDate[day] = 31;

    if (newDate[month] > 12) newDate[month] = 1;
    else if (newDate[month] < 1) newDate[month] = 12;

    if (newDate[year] > 99) newDate[year] = 0;
    else if (newDate[year] < 0) newDate[year] = 99;
}

int buttonPressed(){
    int frontReading = readAvgAnalog(frontButtons, 25, 0);

    if (isInRange(frontReading, al1ButtonVal, buttonRange))
        return al1Button;
    else if (isInRange(frontReading, upButtonVal, buttonRange))
        return upButton;
    else if (isInRange(frontReading, downButtonVal, buttonRange))
        return downButton;
    else if (isInRange(frontReading, al2ButtonVal, buttonRange))
        return al2Button;

    int rearReading = readAvgAnalog(rearButtons, 5, 2);

    if (isInRange(rearReading, modeButtonVal, buttonRange))
        return modeButton;
    else if (isInRange(rearReading, setButtonVal, buttonRange))
        return setButton;

    return 0;
}

bool isInRange(int value, int compare, int range){
    return(
        value >= (compare - range)
        && value <= (compare + range)
    );
}

int readAvgAnalog(int pin, byte numReadings, int readingDelay){
    int readingsTotal = 0;

    for (int i = 0; i < numReadings; i++) {
        readingsTotal += analogRead(pin);
        delay(readingDelay);
    }

    return readingsTotal / numReadings;
}

void updateBrightness(){
    int brightness = map(readAvgAnalog(ldrPin,5,2), ldrDark, ldrBright, minBrightness, maxBrightness);
    int brightnessPercent = constrain(brightness, minBrightness, maxBrightness);

    if (brightnessPercent > lastBrightness) {
        brightnessPercent = lastBrightness + 1;
    }else if (brightnessPercent < lastBrightness) {
        brightnessPercent = lastBrightness - 1;
    }

    lastBrightness = brightnessPercent;

    // Exponential dimming
    brightness = pow (2, (brightnessPercent / R)) - 1;

    // Set the anode driver output to the calculated brightness
    analogWrite(anodes, brightness);
}

void setBrightness(int brightness){
    analogWrite(anodes, brightness);
}

void fadeTo(int* time, int* prevTime, int duration){
    float phaseDuration = 1000 * duration / fadeSteps;

    for (int phase = 1; phase <= fadeSteps; phase++) {
        displayTime(prevTime);
        delayMicroseconds(
            phaseDuration * (fadeSteps-phase) / fadeSteps + 1
        );
        displayTime(time);
        delayMicroseconds(
            phaseDuration * phase / fadeSteps
        );
    }
}

void displayTime(int* time){
    for (int i = 2; i >= 0; i--) {
        if (time[i] > 99) {
            shift10(dataPin, clkPin, blank);
            shift10(dataPin, clkPin, blank);
        } else {
            shift10(dataPin, clkPin, numbers[(int) time[i] % 10]);
            shift10(dataPin, clkPin, numbers[(int) time[i] / 10]);
        }
    }

    digitalWrite(strobePin, HIGH);
    digitalWrite(strobePin, LOW);
}

void clearDisplay(){
    int clearTime[3] = { 100, 100, 100 };
    displayTime(clearTime);
}

void cleanCathodes(){
        int randomDigits[3] = {
            random(0,99),
            random(0,99),
            random(0,99)
        };
        displayTime(randomDigits);
}

// MSB first
void shift10(uint8_t dataPin, uint8_t clockPin, short val){
    for (int i = 0; i < 10; i++) {
        digitalWrite(dataPin, !!(val & (1 << (9 - i))));

        digitalWrite(clockPin, HIGH);
        digitalWrite(clockPin, LOW);
    }
}

void setupNixies(){
    pinMode(dataPin, OUTPUT);
    pinMode(al1Light, OUTPUT);
    pinMode(al2Light, OUTPUT);

    digitalWrite(al1Light, LOW);
    digitalWrite(al2Light, LOW);

    setBrightness(150);

    pinMode(clkPin, OUTPUT);
    pinMode(strobePin, OUTPUT);
    pinMode(anodes, OUTPUT);
    pinMode(decimalPoint, OUTPUT);

    digitalWrite(strobePin, LOW);
    analogWrite(anodes, 0);
}

void stop_SPI(){
    SPI.end();
}

void start_SPI(){
    SPI.begin();
    SPI.setBitOrder(MSBFIRST);
    SPI.setDataMode(SPI_MODE1);
}

void RTC_init(){
    pinMode(csPin,OUTPUT);

    SPI.begin();
    SPI.setBitOrder(MSBFIRST);
    SPI.setDataMode(SPI_MODE1); // both mode 1 & 3 should work
    // Set control register
    digitalWrite(csPin, LOW);
    SPI.transfer(0x8E);
    // 60 = disable Oscillator and Battery SQ wave @1hz,
    // temp compensation, Alarms disabled
    SPI.transfer(0x60);
    digitalWrite(csPin, HIGH);
    delay(10);
}

void setDateTime(int* date, int* time){
    int TimeDate [7]={
        time[seconds], time[minutes], time[hours],
        0, // DOW, not used
        date[day], date[month], date[year]
    };
    for(int i = 0; i < 7; i++){
        if(i == 3)
            i++;
        int b = TimeDate[i] / 10;
        int a = TimeDate[i]-b * 10;
        if(i == 2){
            if (b == 2)
                b = B00000010;
            else if (b == 1)
                b = B00000001;
        }
        TimeDate[i] = a + (b<<4);

        digitalWrite(csPin, LOW);
        SPI.transfer(i + 0x80);
        SPI.transfer(TimeDate[i]);
        digitalWrite(csPin, HIGH);
    }
}

void readDateTime(){
    int TimeDate [7]; //seconds,minutes,hours,dow,day,month,year
    for(int i=0; i < 7; i++){
        if(i == 3)
            i = 4;
        digitalWrite(csPin, LOW);
        SPI.transfer(i+0x00);
        unsigned int n = SPI.transfer(0x00);
        digitalWrite(csPin, HIGH);
        int a=n & B00001111;
        if(i==2){
            int b=(n & B00110000)>>4; //24 hour mode
            if(b==B00000010)
                b=20;
            else if(b==B00000001)
                b=10;
            TimeDate[i]=a+b;
        }
        else if(i==4){
            int b=(n & B00110000)>>4;
            TimeDate[i]=a+b*10;
        }
        else if(i==5){
            int b=(n & B00010000)>>4;
            TimeDate[i]=a+b*10;
        }
        else if(i==6){
            int b=(n & B11110000)>>4;
            TimeDate[i]=a+b*10;
        }
        else{
            int b=(n & B01110000)>>4;
            TimeDate[i]=a+b*10;
        }
    }
    date[day] = TimeDate[4];
    date[month] = TimeDate[5];
    date[year] = TimeDate[6];
    time[hours] = TimeDate[2];
    time[minutes] = TimeDate[1];
    time[seconds] = TimeDate[0];
}

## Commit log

2015-06-23 Initial commit
    Design files, arduino code
    [Nixieclock.brd, Nixieclock.sch]
2015-06-23 Updated schematic
    [Nixieclock.sch]
2018-02-02 Add BOM
    [BOM.ods]

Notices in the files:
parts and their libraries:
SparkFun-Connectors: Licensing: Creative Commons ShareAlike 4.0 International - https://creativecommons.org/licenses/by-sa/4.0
